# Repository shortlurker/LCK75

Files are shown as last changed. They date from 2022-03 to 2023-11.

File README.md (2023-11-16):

# LCK75 SL Mod

This is a modification of Lysol's <a href="https://github.com/lyso1/LCK75">LCK75 Rev1</a>. A 75% through-hole keyboard originally designed by <a href="https://github.com/lyso1">Lysol</a>.

#### LCK75 main PCB changes:

- Keyswitch footprints replaced with MXOnly-*U-Hotswap-Antishear footprints for Kailh hotswap sockets.
- Removed optional modifier, spacebar and keyswitch instead of the rotary encoder footprints.
- Diode and resistor footprints replaced with 5.08mm pin pitch footprints for more physical space.
- Added diode rows.
- Swapped OLED display positions with buttons and ISP header.
- Crystal and filter caps have been moved beside the corresponding pins on the ATmega.
- USB-C connector unfortunately has been mirroed across the center to the right. I didn't like any of the ways I could route the data traces near the diodes if the connector was not moved.
- Other components have been pushed around for clearance of the repositioned USB-C connector.
- Art adjusted.

#### Switch plate changes:

- Removed optional modifier and spacebar openings.
- Extended top edge of the plate by 1mm and removed any thin sections to reduce the risk of breaking during manufacturing.
- Reduced holes down to support m2 screws and added two additional holes for case/trim mounting options.

#### The bottom PCB, foam and acrylic guard files have not been changed.

#### Notes: 

- <a href="https://octopart.com/bom-tool/kmsRsySl">BOM</a> of the parts used in the build.
- If you already own a LCK75 then all you need is the main PCB.
- Works with up to date QMK/VIA LCK75 FW. If porting to VIAL one will need to increase the total number of columns by one in vial.json as a column matrix number is skipped in the QMK FW. 
- The Kailh hotswap sockets may add bit of additional gap between the main PCB and the bottom PCB depending on the density of the foam.
- Existing cases made for the original LCK75 will not work with this PCB because of the repositioned USB-C connector. I am not responsible for any damages if you attempt to modify an existing case.

Any questions or feedback of this specific edit of the LCK75 please leave here.

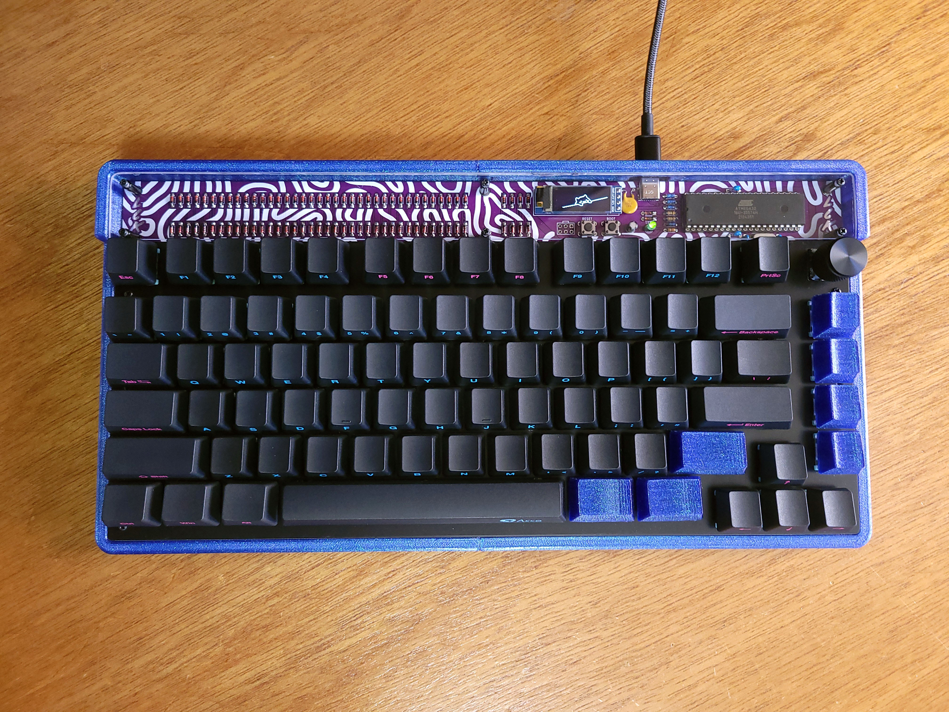
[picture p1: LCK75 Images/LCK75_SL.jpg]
LCK75_SL


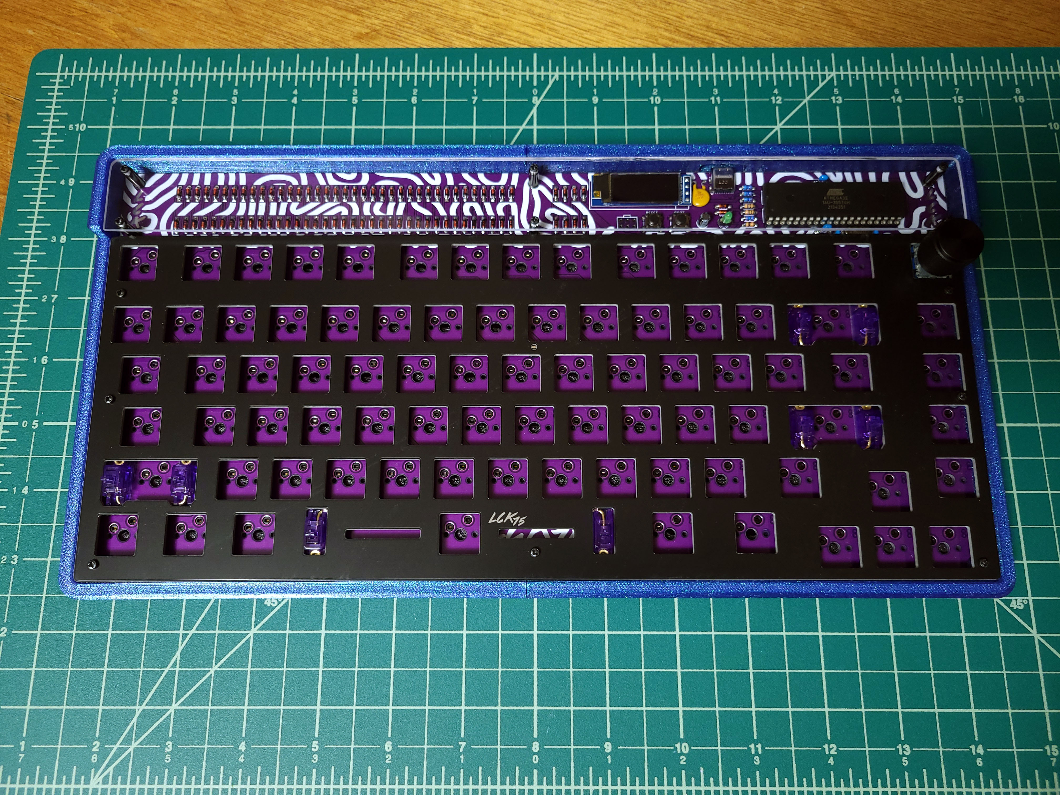
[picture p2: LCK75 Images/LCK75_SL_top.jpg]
LCK75_SL_top


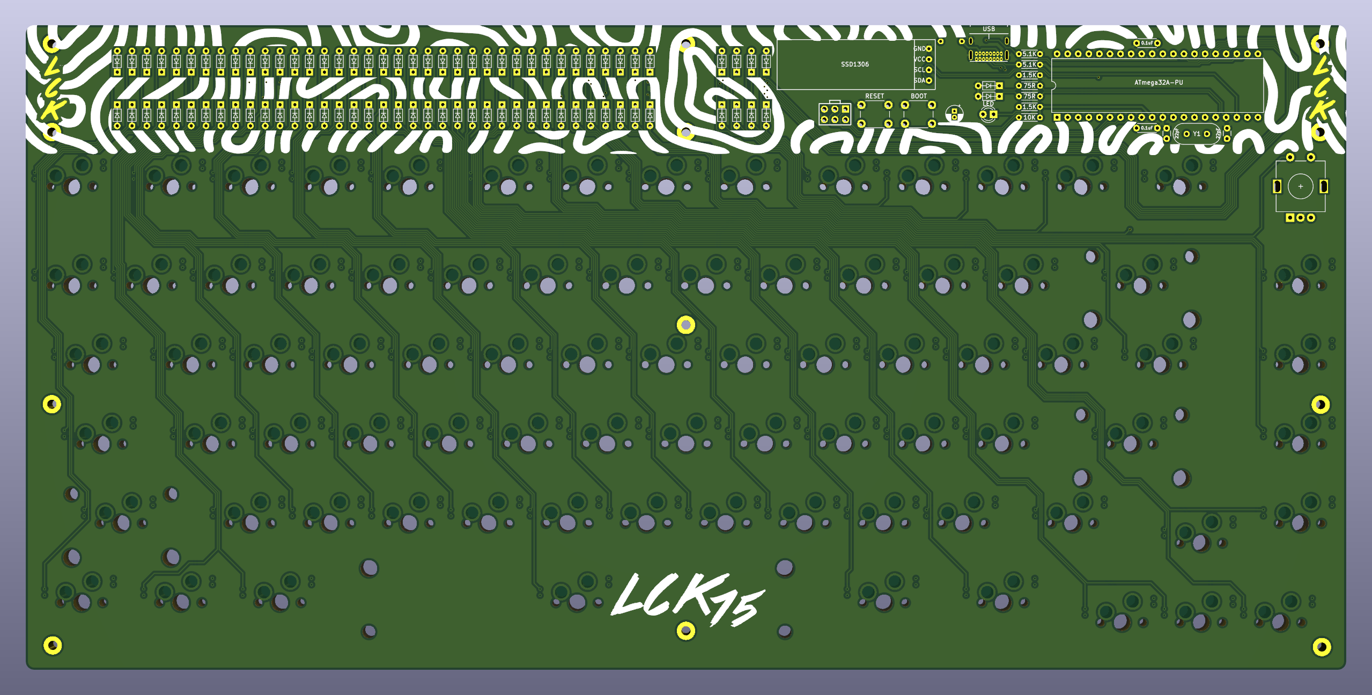
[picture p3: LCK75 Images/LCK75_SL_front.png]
LCK75_SL_front


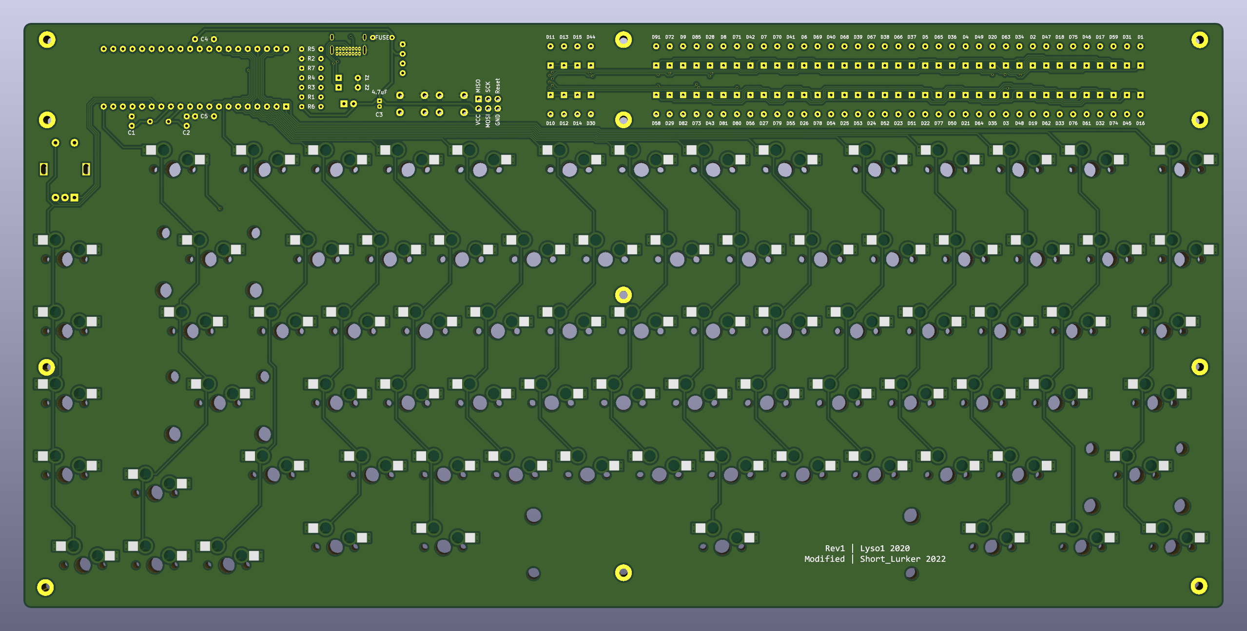
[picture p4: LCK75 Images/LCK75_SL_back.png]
LCK75_SL_back


<br />This work is licensed under a <a rel="license" href="http://creativecommons.org/licenses/by/4.0/">Creative Commons Attribution 4.0 International License</a>.

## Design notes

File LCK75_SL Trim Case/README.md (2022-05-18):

#### Trim case .step files for the LCK75_SL.

An attempt at a top mountish case. The pictures of the completed keyboard with the 3D printed case trim are from these files.

- All holes are for M2 screws.
- The top pieces slide in between the keyplate and PCB. 
- The raised rear section to enclose the acrylic guard was designed to use 10mm M2 standoffs with a 3mm thick acrylic guard for a flush finish. In my pictures I used 0.08" (~2mm) thick acrylic.
- The bottom pieces attach to the bottom PCB and is joined to the top with screws around the permieter.
- Depending on the density, A 5mm thick foam with cutouts for the hotswap sockets can be used. 3mm thick foam without cutouts can be used.

#### Notes:
- Mounting tabs for the PCB are based on the unmodified PCB holes.
- Two addional tabs added under the ESC and rotary encoder for the modified keyswitch plate.
- Holes under the third row (middle) are too close to the keyswitch and depending on the style of screw used the screw head can block the keyswitch from being quickly hotswappable.
- There might be some issues with holes not lining up with the PCB as the switch plate and main PCB dimensions are not identical. Lining them up prior to creating the case pieces was done as best as I could.

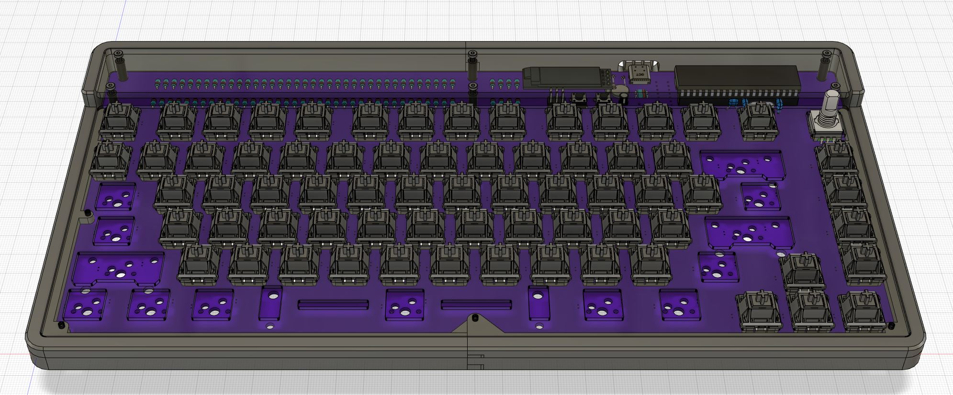
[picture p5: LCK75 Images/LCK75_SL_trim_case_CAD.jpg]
LCK75_SL_trim_case_CAD


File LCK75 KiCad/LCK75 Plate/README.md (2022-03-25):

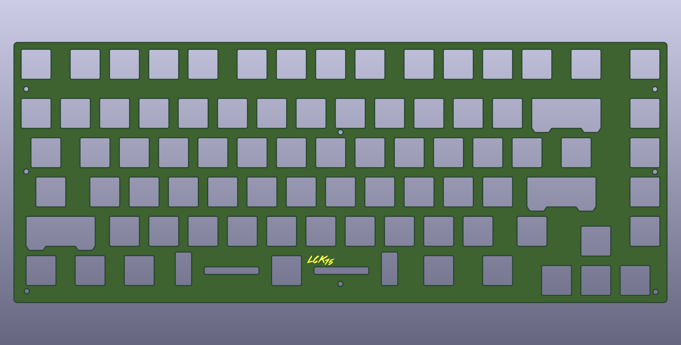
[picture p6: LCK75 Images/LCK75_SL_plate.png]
LCK75_SL_plate


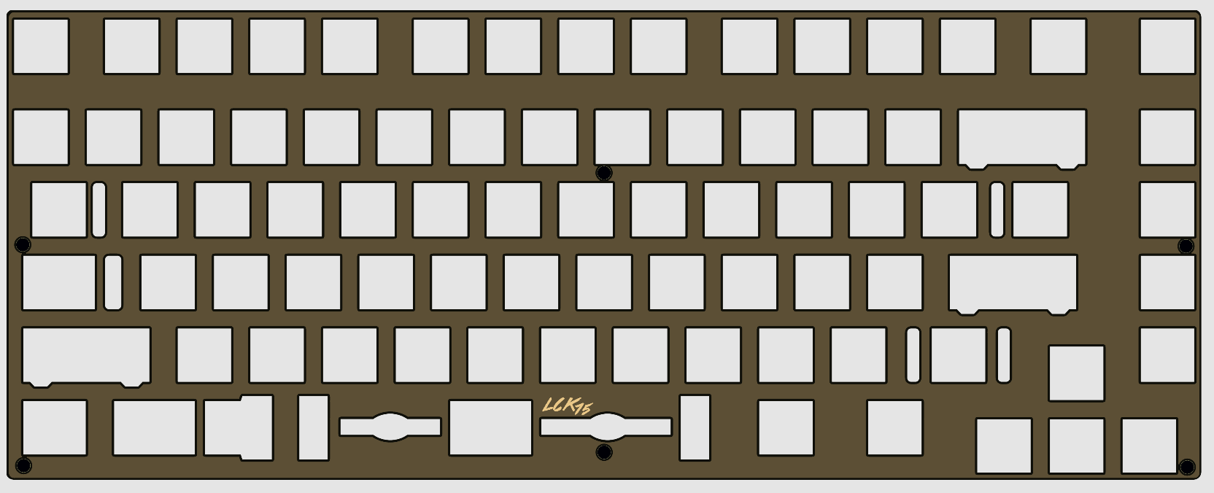
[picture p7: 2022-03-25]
Original Files/LCK75 images/lck pcb designs - Imgur.png

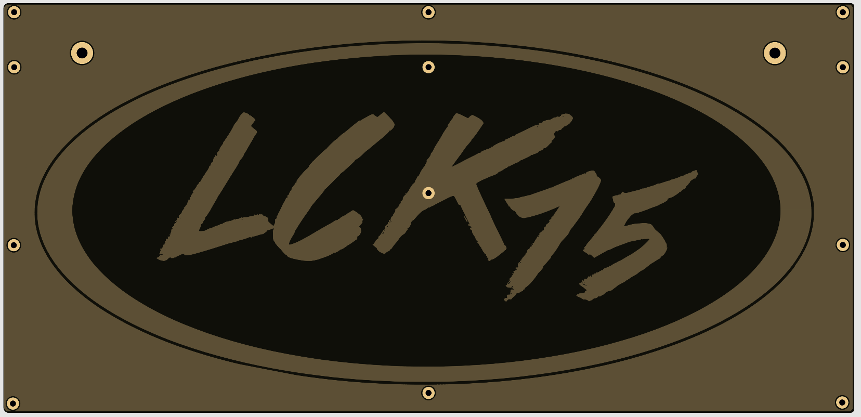
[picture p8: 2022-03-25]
Original Files/LCK75 images/lck pcb designs - Imgur (1).png

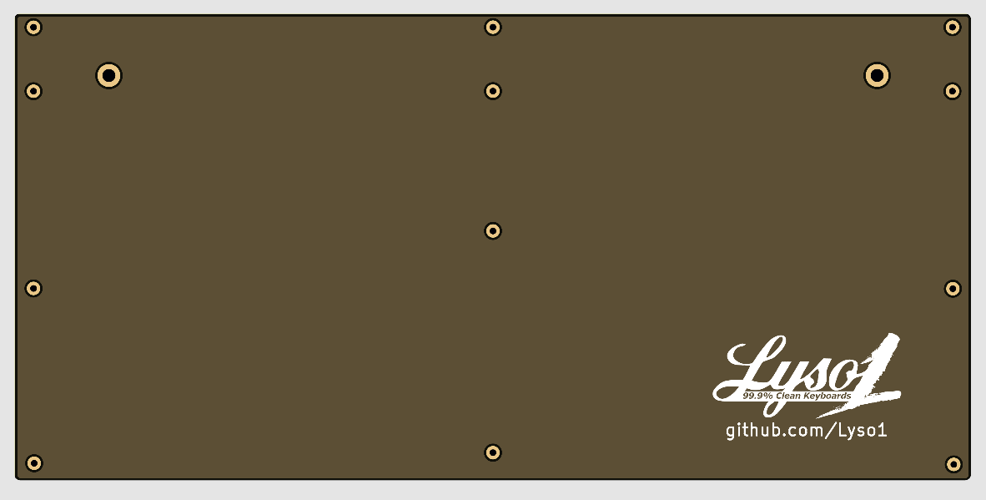
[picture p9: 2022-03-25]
Original Files/LCK75 images/lck pcb designs - Imgur (2).png

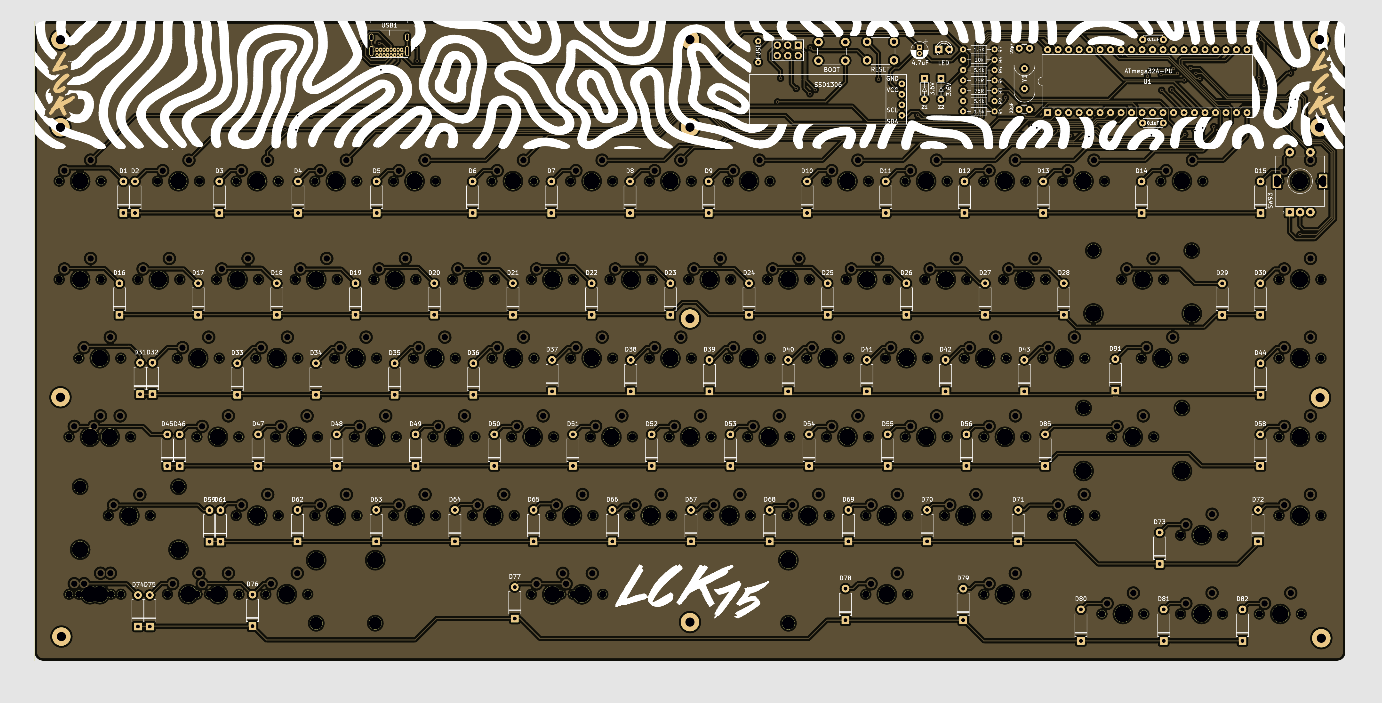
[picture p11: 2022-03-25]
Original Files/LCK75 images/mainboard.png

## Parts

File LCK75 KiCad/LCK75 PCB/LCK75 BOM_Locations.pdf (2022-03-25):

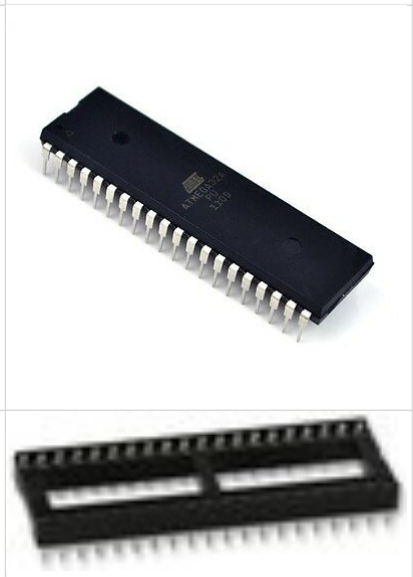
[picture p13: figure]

Location | Component
U1 | ATMEGA32A-PU

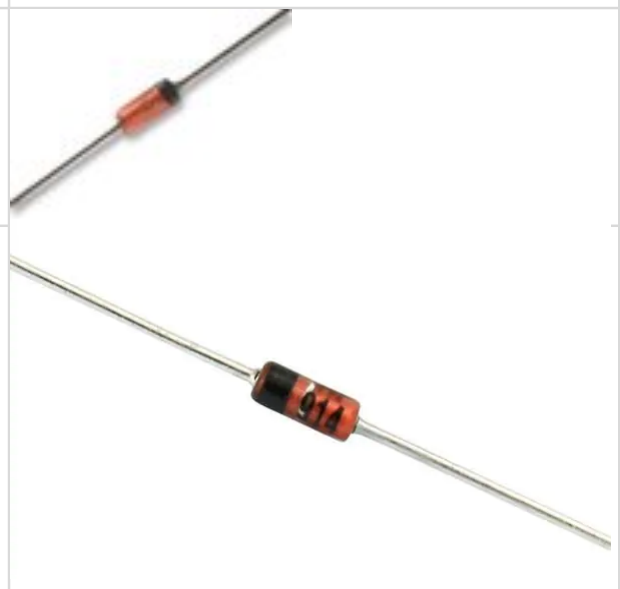
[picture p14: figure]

U1 | IC Socket
D1-D82 | through hole diodes/ 512-1N4148TR
Z1,Z2 | 3.6v Zener diodes

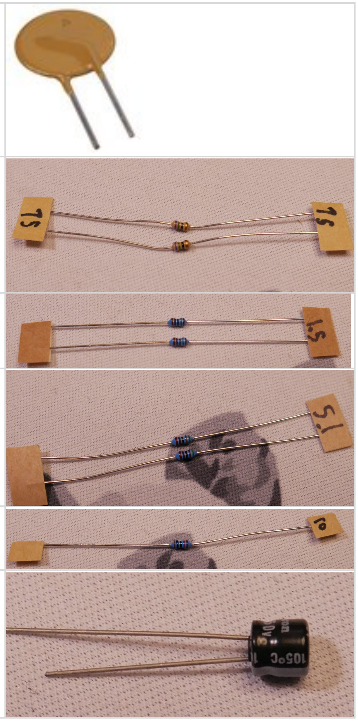
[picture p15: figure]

FUSE | 500mA fuse
R3,R4 | 75 ohm resistor
R1,R7 | 1.5k ohm resistor
R2,R5 | 5.1k ohm resistor
R6 | 10k ohm resistor
4.7uF | 4.7uF cylindrical capacitor

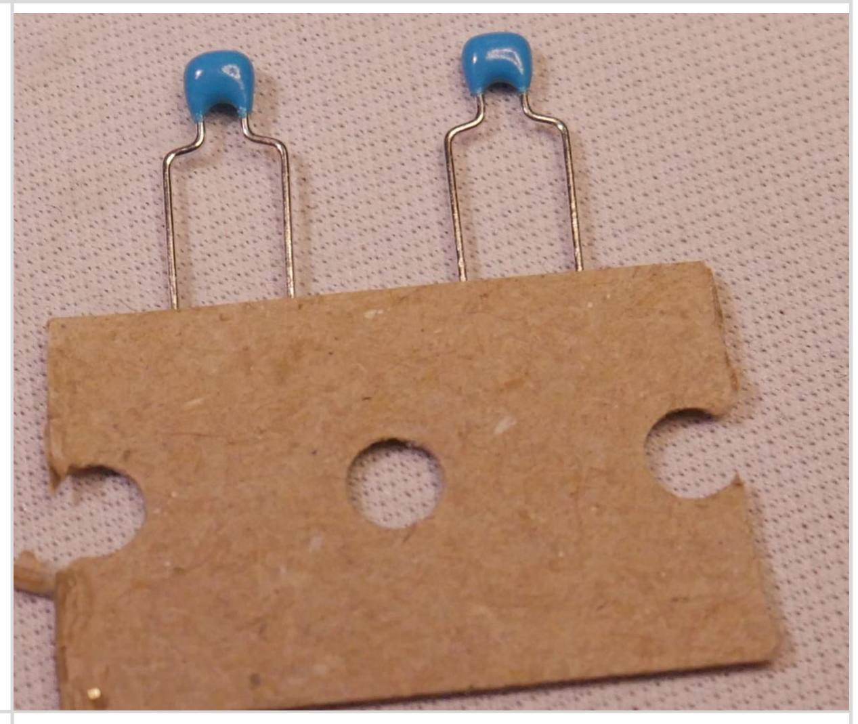
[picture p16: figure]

0.1uF | capacitors that go next to the microcontroller

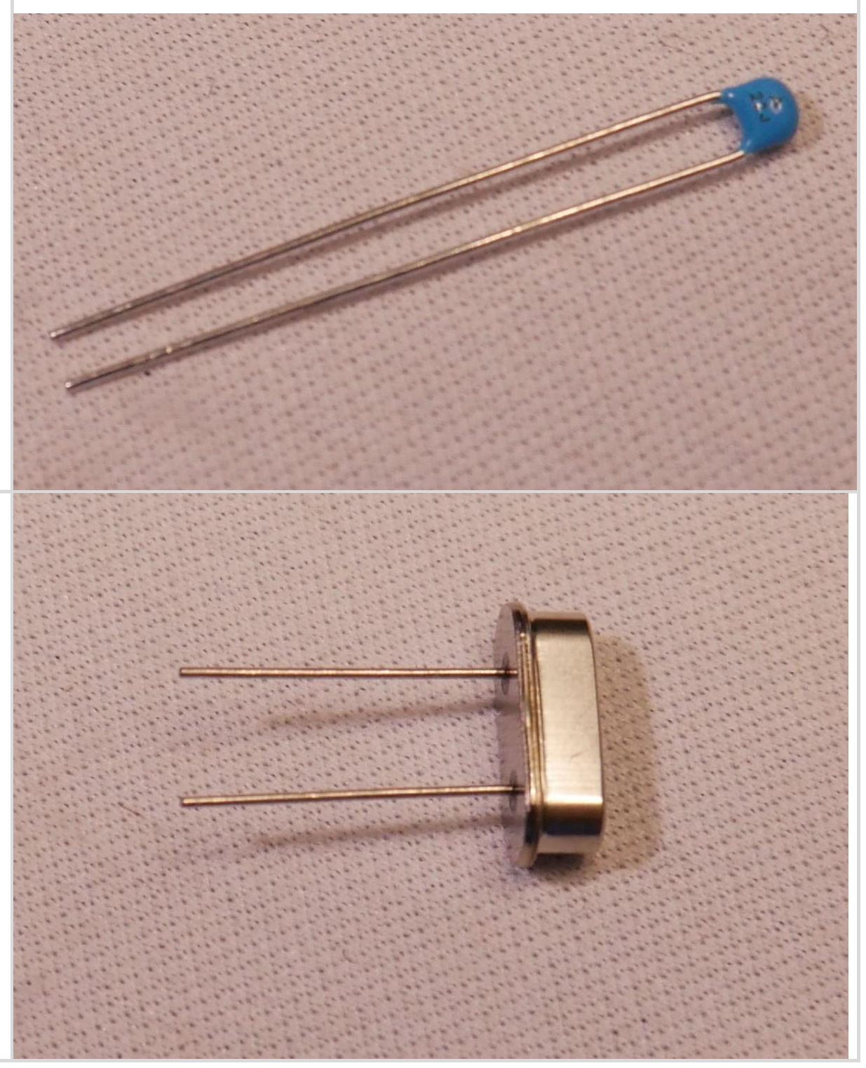
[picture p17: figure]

22pF | capacitors that goes between the crystal on the mainboard
Y1 | Crystal

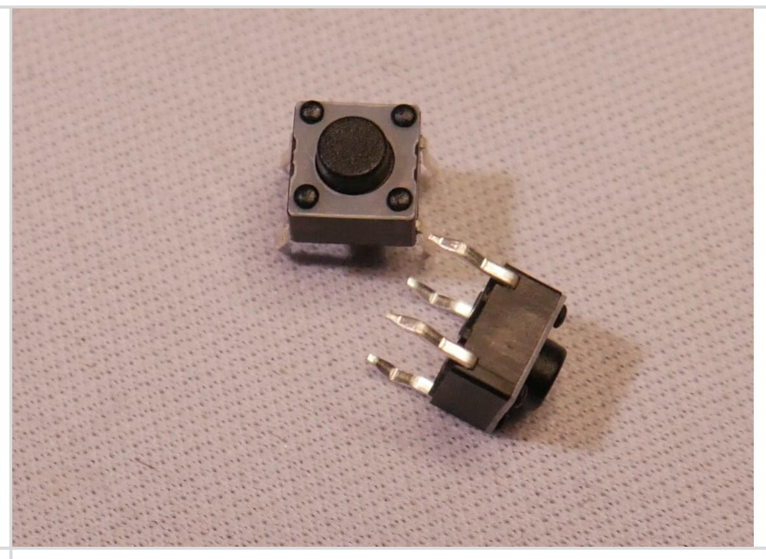
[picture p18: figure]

BOOT,RESET | 6mm push button
SW93 | Rotary Encoder
SSD1306 | OLED Screen
LED | LED
USB1 | USB C Connector

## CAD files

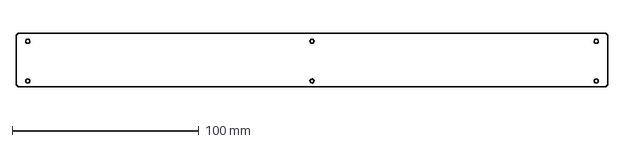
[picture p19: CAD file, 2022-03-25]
LCK75 KiCad/LCK75 Foam & Guard/LCK75-acrylic-guard.dxf
317.2 x 28.9 mm

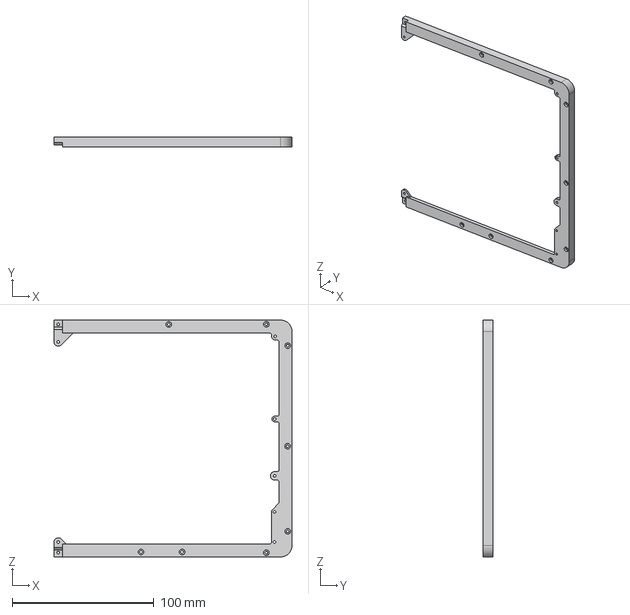
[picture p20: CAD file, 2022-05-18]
LCK75_SL Trim Case/bottom_right.step
167.7 x 7.00 x 167.0 mm

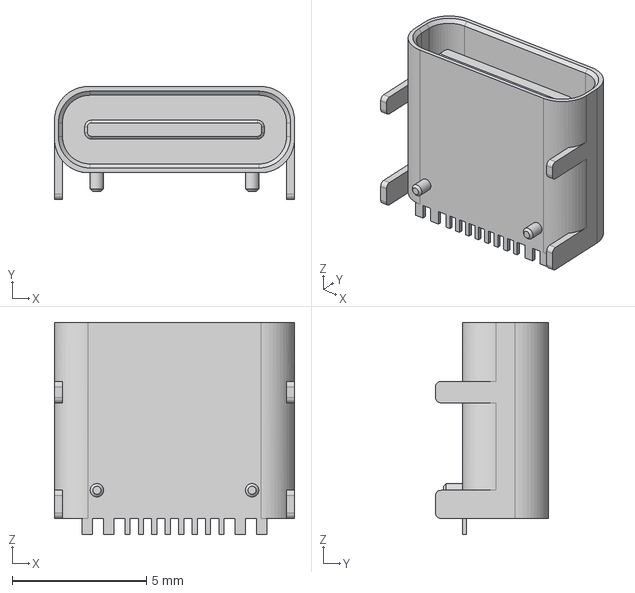
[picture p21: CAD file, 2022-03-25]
Original Files/LCK75 kicad libs/Type-C.pretty-master/Type-C.pretty-master/HRO TYPE-C-31-M-12.step
8.94 x 4.21 x 7.90 mm

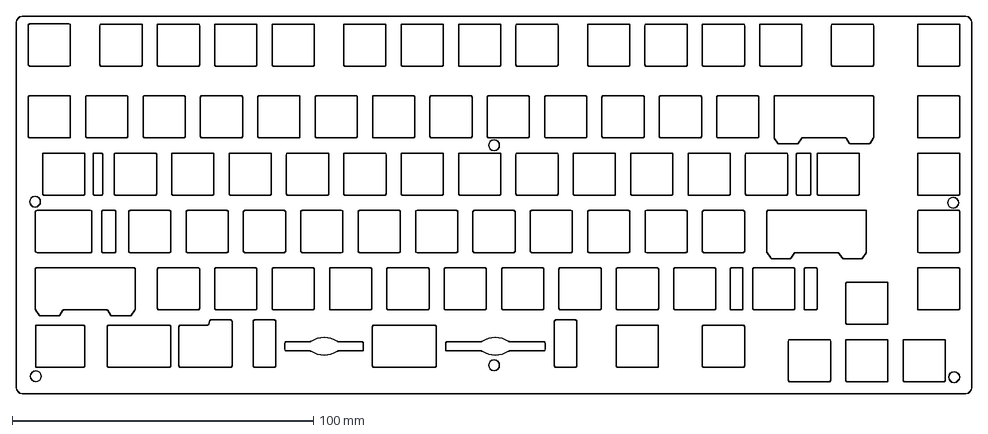
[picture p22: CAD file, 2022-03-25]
Original Files/LCK75gerbers&parts/LCK75PLATE/LCK75-KITPLATErev1.dxf
317.3 x 125.3 mm

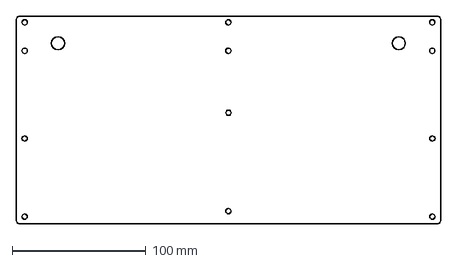
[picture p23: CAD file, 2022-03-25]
Original Files/LCK75gerbers&parts/LCKFOAM&GUARD/LCKFOAM.dxf
317.3 x 154.8 mm

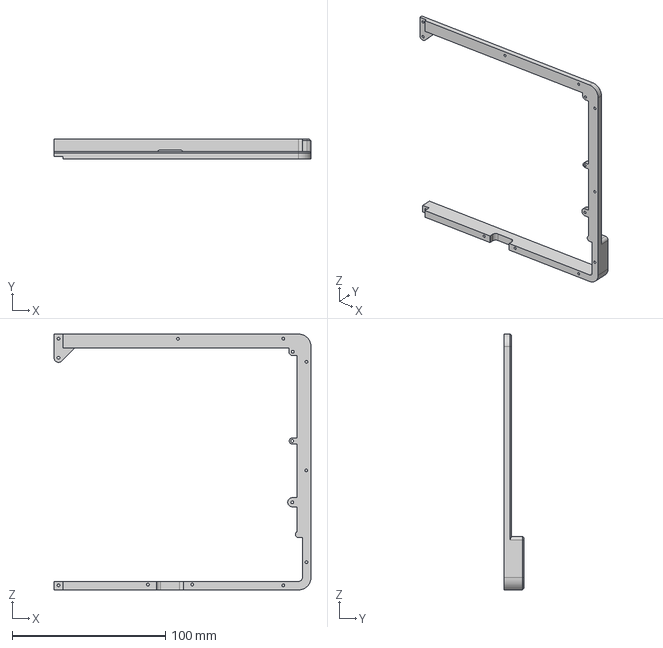
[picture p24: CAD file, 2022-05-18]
LCK75_SL Trim Case/top_right.step
167.7 x 13.0 x 167.0 mm

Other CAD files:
LCK75_SL Trim Case/bottom_left.step
LCK75_SL Trim Case/top_left.step

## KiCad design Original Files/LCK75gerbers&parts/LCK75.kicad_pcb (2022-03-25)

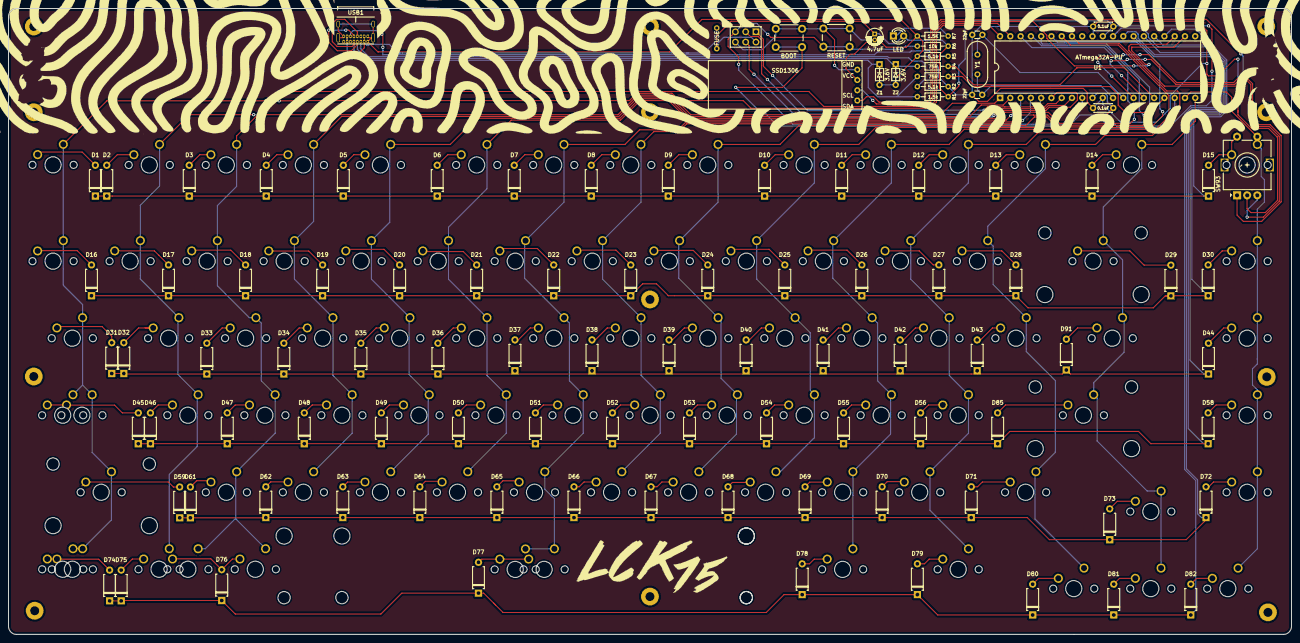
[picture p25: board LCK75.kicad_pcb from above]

Board: 2 copper layers, 317.3 x 154.8 mm, 192 parts (1 on the bottom side), 124 nets.

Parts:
C1, C2: 22pF; C_Disc_D3.0mm_W1.6mm_P2.50mm
C3: 4.7uF; CP_Radial_D4.0mm_P1.50mm
C4, C5: 0.1uF; C_Disc_D4.3mm_W1.9mm_P5.00mm
D1, D2, D3, D4, D5, D6, D7, D8, D9, D10, D11, D12, D13, D14, D15, D16, D17, D18, D19, D20, D21, D22, D23, D24, D25, D26, D27, D28, D29, D30, D31, D32, D33, D34, D35, D36, D37, D38, D39, D40, D41, D42, D43, D44, D45, D46, D47, D48, D49, D50, D51, D52, D53, D54, D55, D56, D58, D59, D61, D62, D63, D64, D65, D66, D67, D68, D69, D70, D71, D72, D73, D74, D75, D76, D77, D78, D79, D80, D81, D82, D85, D91: 1N4148; D_A-405_P7.62mm_Horizontal
F1: 500mA; polyfuse_5.1mm
J1: AVR-ISP-6; AVR_ICSP_3x2
LED: POWER; LED_D3.0mm
R1: 1.5k; R_Axial_DIN0204_L3.6mm_D1.6mm_P7.62mm_Horizontal
R2, R5: 5.1k; R_Axial_DIN0204_L3.6mm_D1.6mm_P7.62mm_Horizontal
R3, R4: 75R; R_Axial_DIN0204_L3.6mm_D1.6mm_P7.62mm_Horizontal
R6: 10k; R_Axial_DIN0204_L3.6mm_D1.6mm_P7.62mm_Horizontal
R7: 1.5K; R_Axial_DIN0204_L3.6mm_D1.6mm_P7.62mm_Horizontal
SSD1306: OLED; ssd1306 128x32 oled
SW1, SW2, SW3, SW4, SW5, SW6, SW7, SW8, SW9, SW10, SW11, SW12, SW13, SW14, SW15, SW16, SW17, SW18, SW19, SW20, SW21, SW22, SW23, SW24, SW25, SW26, SW27, SW28, SW30, SW32, SW33, SW34, SW35, SW36, SW37, SW38, SW39, SW40, SW41, SW42, SW43, SW45, SW46, SW48, SW49, SW50, SW51, SW52, SW53, SW54, SW55, SW56, SW57, SW58, SW61, SW65, SW66, SW67, SW68, SW69, SW70, SW71, SW72, SW73, SW74, SW76, SW77, SW84, SW85, SW86: SW_SPST; MXOnly-1U-NoLED
SW29: SW_SPST; MXOnly-2U-NoLED
SW31, SW44, SW82, SW83, SW88, SW89: SW_SPST; MXOnly-1.5U-NoLED
SW47, SW75: SW_SPST; MXOnly-1.75U-NoLED
SW60, SW63: SW_SPST; MXOnly-2.25U-NoLED
SW78, SW79, SW80: SW_SPST; MXOnly-1.25U-NoLED
SW81: SW_SPST; MXOnly-7U-ReversedStabilizers-NoLED
SW87, SW91: SW_PUSH-keyboard_parts; SW_PUSH_6mm
SW90: SW_SPST; MXOnly-6.25U-ReversedStabilizers-NoLED
SW93: Rotary_Encoder_Switch; RotaryEncoder_Alps_EC11E-Switch_Vertical_H20mm-new
U1: ATmega32A-PU; DIP-40_W15.24mm
USB1: Type-C_USB_C_GCT_USB4085; USB_C_GCT_USB4085
Y1: Crystal; Crystal_HC49-4H_Vertical
Z1, Z2: 3.6V; D_DO-35_SOD27_P5.08mm_Horizontal

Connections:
D+: R4.1, U1.16
D-: R3.1, U1.17
EC11-A: SW93.A, U1.14
EC11-B: SW93.B, U1.15
EC11-GND: C1.2, C2.2, C3.2, C4.2, C5.2, J1.6, R2.1, R5.2, R7.2, SSD1306.4, SW87.1, SW91.1, SW93.C, U1.11, U1.31, USB1.A1, USB1.B1, USB1.B12, USB1.S1, Z1.2, Z2.2
MISO: J1.1, U1.7
MOSI: J1.4, U1.6
unnamed: C1.1, U1.13, Y1.1
unnamed: C2.1, U1.12, Y1.2
unnamed: D1.2, SW1.1
unnamed: D2.2, SW2.1
unnamed: D3.2, SW3.1
unnamed: D4.2, SW4.1
unnamed: D5.2, SW5.1
unnamed: D6.2, SW6.1
unnamed: D7.2, SW7.1
unnamed: D8.2, SW8.1
unnamed: D9.2, SW9.1
unnamed: D10.2, SW10.1
unnamed: D11.2, SW11.1
unnamed: D12.2, SW12.1
unnamed: D13.2, SW13.1
unnamed: D14.2, SW14.1
unnamed: D15.2, SW15.1, SW93.S2
unnamed: D16.2, SW16.1
unnamed: D17.2, SW17.1
unnamed: D18.2, SW18.1
unnamed: D19.2, SW19.1
unnamed: D20.2, SW20.1
unnamed: D21.2, SW21.1
unnamed: D22.2, SW22.1
unnamed: D23.2, SW23.1
unnamed: D24.2, SW24.1
unnamed: D25.2, SW25.1
unnamed: D26.2, SW26.1
unnamed: D27.2, SW27.1
unnamed: D28.2, SW28.1
unnamed: D29.2, SW29.1
unnamed: D30.2, SW30.1
unnamed: D31.2, SW31.1
unnamed: D32.2, SW32.1
unnamed: D33.2, SW33.1
unnamed: D34.2, SW34.1
unnamed: D35.2, SW35.1
unnamed: D36.2, SW36.1
unnamed: D37.2, SW37.1
unnamed: D38.2, SW38.1
unnamed: D39.2, SW39.1
unnamed: D40.2, SW40.1
unnamed: D41.2, SW41.1
unnamed: D42.2, SW42.1
unnamed: D43.2, SW43.1
unnamed: D44.2, SW45.1
unnamed: D45.2, SW46.1, SW47.1
unnamed: D46.2, SW48.1
unnamed: D47.2, SW49.1
unnamed: D48.2, SW50.1
unnamed: D49.2, SW51.1
unnamed: D50.2, SW52.1
unnamed: D51.2, SW53.1
unnamed: D52.2, SW54.1
unnamed: D53.2, SW55.1
unnamed: D54.2, SW56.1
unnamed: D55.2, SW57.1
unnamed: D56.2, SW58.1
unnamed: D58.2, SW61.1
unnamed: D59.2, SW63.1
unnamed: D61.2, SW65.1
unnamed: D62.2, SW66.1
unnamed: D63.2, SW67.1
unnamed: D64.2, SW68.1
unnamed: D65.2, SW69.1
unnamed: D66.2, SW70.1
unnamed: D67.2, SW71.1
unnamed: D68.2, SW72.1
unnamed: D69.2, SW73.1
unnamed: D70.2, SW74.1
unnamed: D71.2, SW75.1
unnamed: D72.2, SW76.1
unnamed: D73.2, SW77.1
unnamed: D74.2, SW78.1, SW88.1
unnamed: D75.2, SW79.1
unnamed: D76.2, SW80.1, SW89.1
unnamed: D77.2, SW81.1, SW90.1
unnamed: D78.2, SW82.1
unnamed: D79.2, SW83.1
unnamed: D80.2, SW84.1
unnamed: D81.2, SW85.1
unnamed: D82.2, SW86.1
unnamed: R1.2, R3.2, USB1.A7, USB1.B7, Z1.1
unnamed: R4.2, USB1.A6, USB1.B6, Z2.1
unnamed: D85.2, SW60.1
unnamed: D91.2, SW44.1
unnamed: LED.1, R7.1
unnamed: R2.2, USB1.A5
unnamed: R5.1, USB1.B5
SCK: J1.3, U1.8
VCC: F1.2, USB1.A4, USB1.A9, USB1.B4, USB1.B9
boot: SW87.2, U1.18
col0: SW1.2, SW16.2, SW31.2, SW46.2, SW47.2, SW63.2, SW78.2, SW88.2, U1.40
col1: SW2.2, SW17.2, SW32.2, SW48.2, SW79.2, U1.1
col2: SW3.2, SW18.2, SW33.2, SW49.2, SW65.2, SW80.2, SW89.2, U1.39
col3: SW4.2, SW19.2, SW34.2, SW50.2, SW66.2, U1.2
col4: SW5.2, SW20.2, SW35.2, SW51.2, SW67.2, U1.38
col5: SW6.2, SW21.2, SW36.2, SW52.2, SW68.2, U1.3
col6: SW7.2, SW22.2, SW37.2, SW53.2, SW69.2, SW81.2, SW90.2, U1.37
col7: SW8.2, SW23.2, SW38.2, SW54.2, SW70.2, U1.4
col8: SW9.2, SW24.2, SW39.2, SW55.2, SW71.2, U1.36
col9: SW10.2, SW25.2, SW40.2, SW56.2, SW72.2, U1.5
col10: SW11.2, SW26.2, SW41.2, SW57.2, SW73.2, SW82.2, U1.35
col11: SW12.2, SW27.2, SW42.2, SW58.2, SW74.2, SW83.2, U1.34
col12: SW13.2, SW28.2, SW43.2, SW75.2, SW84.2, U1.33
col13: SW14.2, SW29.2, SW44.2, SW60.2, SW77.2, SW85.2, U1.20
col14: SW15.2, SW30.2, SW45.2, SW61.2, SW76.2, SW86.2, SW93.S1, U1.19
oledSCL: SSD1306.2, U1.22
oledSDA: SSD1306.1, U1.23
oledVCC: C3.1, C4.1, C5.1, F1.1, J1.2, LED.2, R1.1, R6.1, SSD1306.3, U1.10, U1.30
reset: J1.5, R6.2, SW91.2, U1.9
row0: D1.1, D2.1, D3.1, D4.1, D5.1, D6.1, D7.1, D8.1, D9.1, D10.1, D11.1, D12.1, D13.1, D14.1, D15.1, U1.24
row1: D16.1, D17.1, D18.1, D19.1, D20.1, D21.1, D22.1, D23.1, D24.1, D25.1, D26.1, D27.1, D28.1, D29.1, D30.1, U1.25
row2: D31.1, D32.1, D33.1, D34.1, D35.1, D36.1, D37.1, D38.1, D39.1, D40.1, D41.1, D42.1, D43.1, D44.1, D91.1, U1.29
row3: D45.1, D46.1, D47.1, D48.1, D49.1, D50.1, D51.1, D52.1, D53.1, D54.1, D55.1, D56.1, D58.1, D85.1, U1.26
row4: D59.1, D61.1, D62.1, D63.1, D64.1, D65.1, D66.1, D67.1, D68.1, D69.1, D70.1, D71.1, D72.1, D73.1, U1.28
row5: D74.1, D75.1, D76.1, D77.1, D78.1, D79.1, D80.1, D81.1, D82.1, U1.27

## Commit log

2022-03-25 Initial upload
    [HRO TYPE-C-31-M-12.step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]
2022-05-18 Add trim case .step files
    [bottom_left.step, bottom_right.step, top_left.step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]
